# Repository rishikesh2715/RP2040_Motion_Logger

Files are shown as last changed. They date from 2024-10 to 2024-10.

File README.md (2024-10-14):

# RP2040 Motion Logger

<p align="center">
  <div>
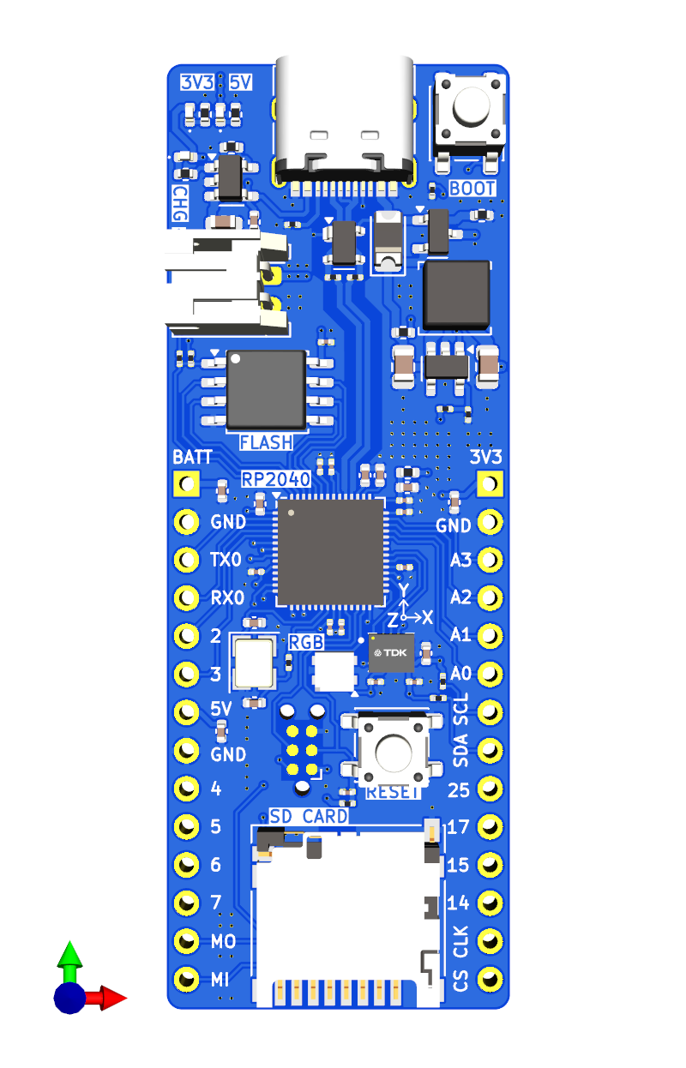
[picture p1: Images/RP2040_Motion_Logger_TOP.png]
    
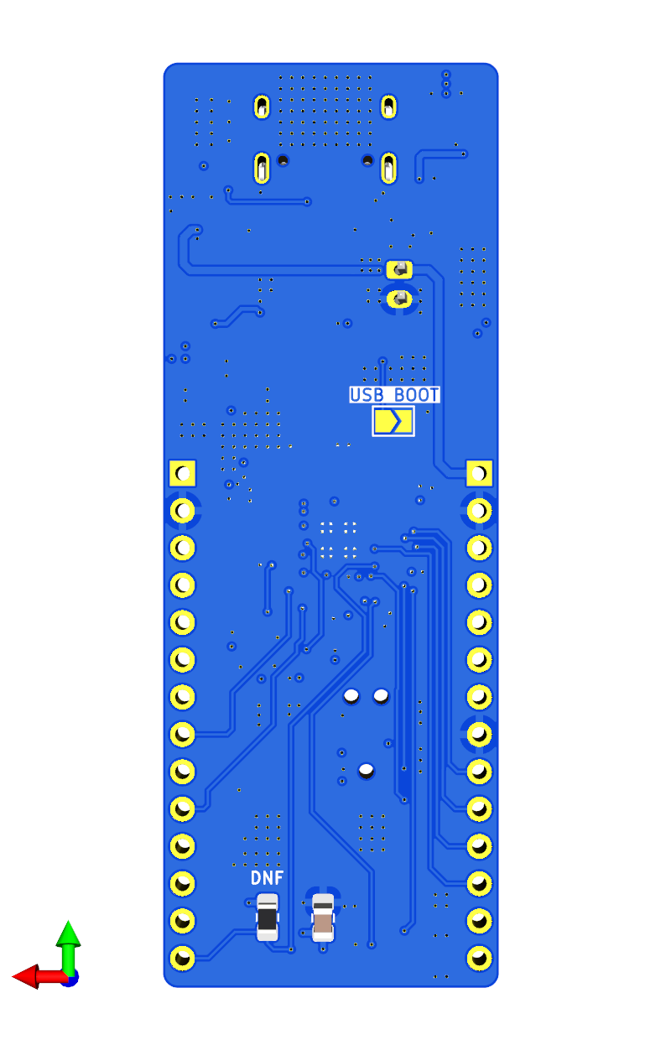
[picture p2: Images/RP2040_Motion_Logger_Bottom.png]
    
  </div>
  <div>
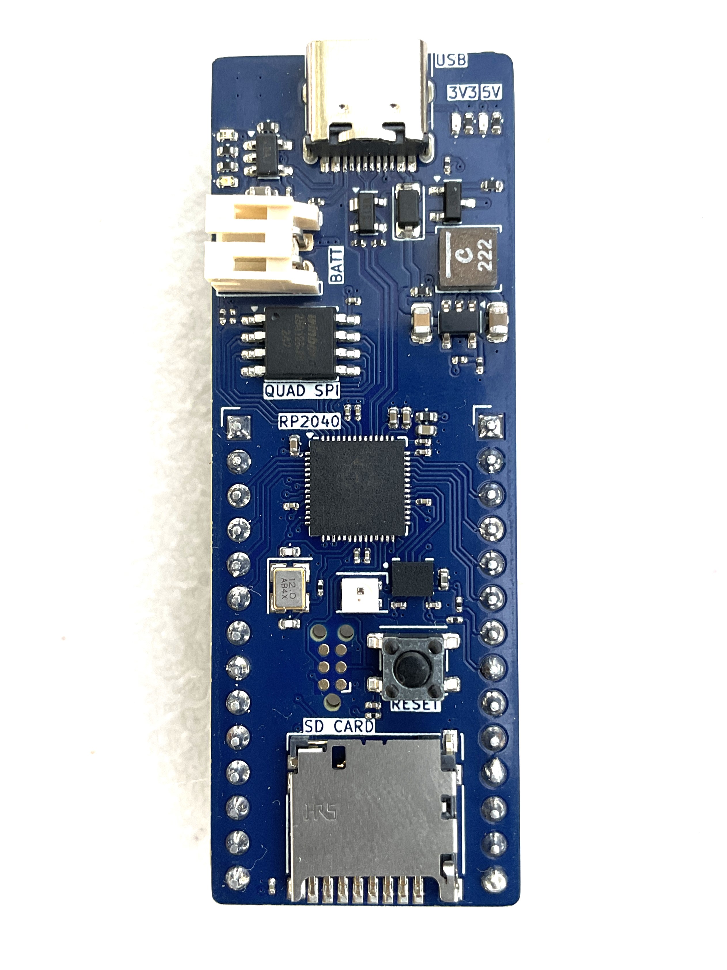
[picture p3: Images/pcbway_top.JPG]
    
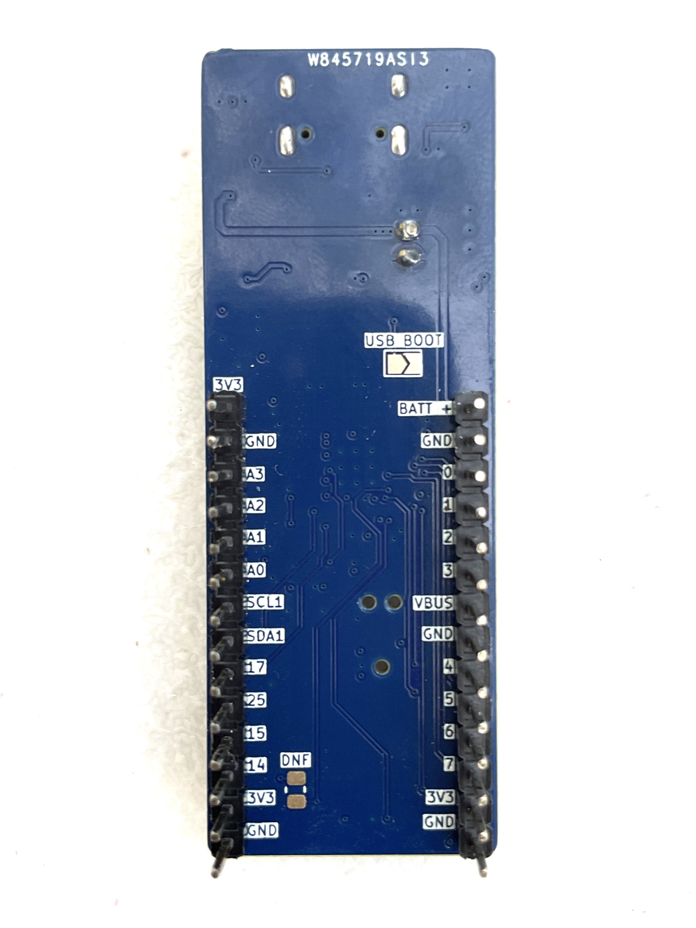
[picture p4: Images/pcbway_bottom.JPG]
    
  </div>
</p>

*I have slightly modified the board to include a bootloader button and made some aesthetic changes since having this board produced. Thus, the produced board slightly looks different. Everything else remains the same*

## Order this Board Through [PCBway](https://www.pcbway.com) 🛫

You can order this board through PCBway for excellent board quality and fast shipping at a very affordable rate. 

- Using PCBway as the manufacturer is recommended because the stackup for this board is based on their specifications. The differential impedance for the USB differential pair has been calculated based on PCBway’s stackup, ensuring that the board will perform as intended when manufactured with them.

- The Bill of Materials (BOM) provided is in PCBway's format. This compatibility ensures a smooth and reliable production experience, reducing the chances of delays due to part sourcing.

To order, simply upload the zip file to PCBway’s portal, select your preferences,
set the Min Track/spacing to 6/6 mil and set the min hole size to 0.2mm. Choosing Immersion Gold(ENIG) as the board finish is recommended but not required, and place your order. PCBway’s user-friendly interface allows for easy customization and order tracking from manufacturing to delivery.

You can learn more about PCBway at the end.

## Interactive PCB Viewer

You can view this board interactively on [KiCanvas](https://kicanvas.org/?github=https%3A%2F%2Fgithub.com%2Frishikesh2715%2FRP2040_Motion_Logger).

## Overview
The RP2040 Motion Logger is a custom microcontroller board based on the RP2040 chip, designed for motion data logging and versatile IoT applications. This compact board (0.9 x 2.48 inches) integrates a wide range of features, making it a powerful tool for projects requiring motion sensing, storage, and connectivity.

### Key Features:
- **Microcontroller**: RP2040 with dual ARM Cortex M0+ processors
- **Motion Sensor**: ICM-42688-P IMU for 6-axis motion tracking
- **Storage**: 128 Mbit Quad SPI Flash Memory and SD Card connector
- **Power Options**: USB Type-C connector or 1S LiPo/Li-ion battery
- **Battery Management**: Onboard charger for 1S LiPo/Li-ion batteries
- **LEDs**: Addressable RGB LED for user indications, plus power status LEDs for both 3.3V and 5V
- **Connectors**:
  - TC2030 JTAG Connector for programming and debugging
  - A set of pin headers including UART, I2C, SPI, ADC, and GPIO pins
- **Power Supply**: 3.3V buck converter supporting up to 2A current
- **Additional Features**: Reset and Bootloader buttons, ESD protection, USB Power, Battery Power, and 3.3V Power pins on headers

### Power Options:
The RP2040 Motion Logger can be powered either via the USB Type-C connector or a 1S LiPo/Li-ion battery. 

### Programming Options:
You can program the board through the USB Type-C connector or the TC2030 JTAG Connector.

## Getting Started
1. **Power Up**: Connect the board via USB Type-C or connect a 1S LiPo/Li-ion battery.
2. **Programming**: Use either the USB connection or JTAG connector with an appropriate debugger to flash your code. (I use VS Code with Raspberry PI PICO Extension)
3. **Bootloader Mode**: Hold down the Bootloader button while connecting the board to USB to enter bootloader mode.
4. **Data Logging**: Use the IMU and available storage to log motion data, or extend functionality via UART, I2C, SPI, and ADC pins.

## Hardware Pinout
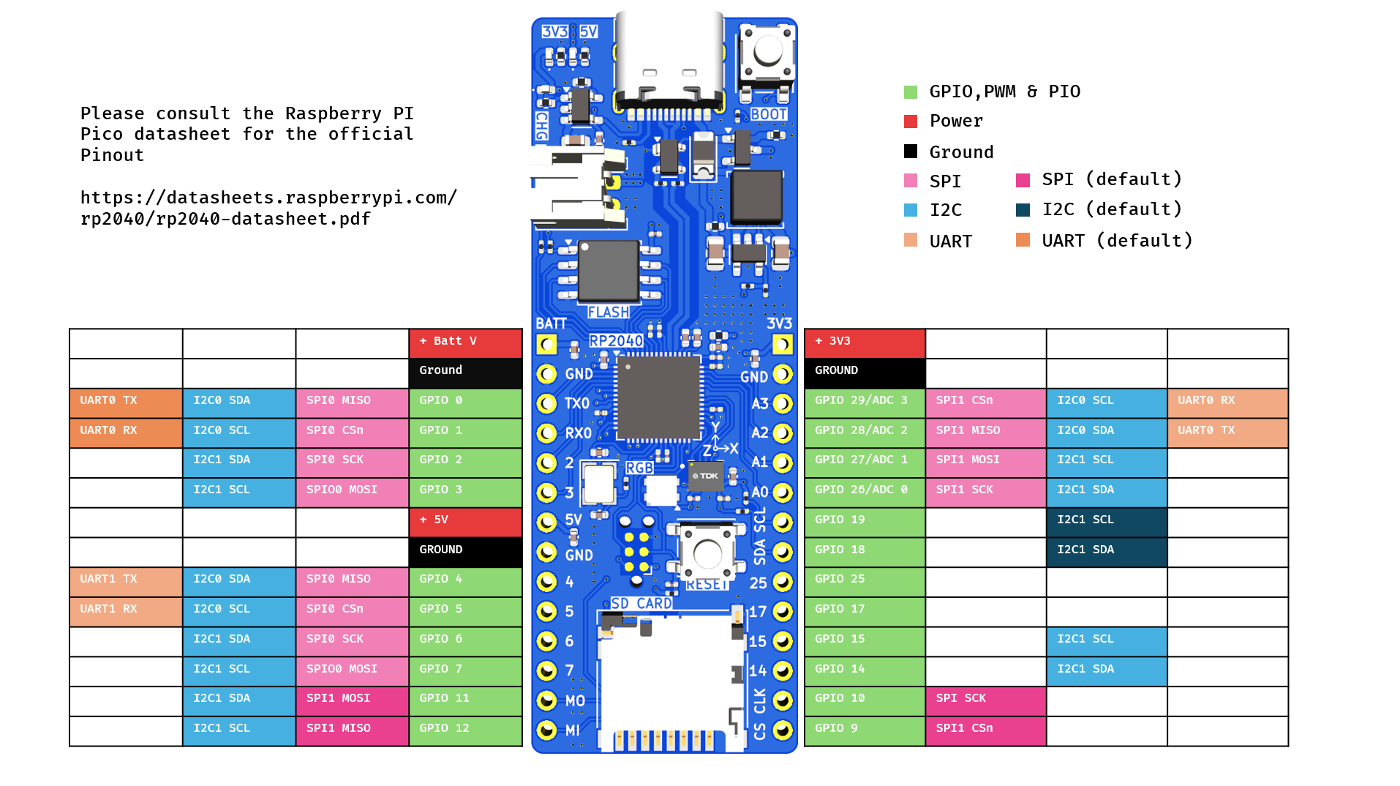
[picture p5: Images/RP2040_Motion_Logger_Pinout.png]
Pinout


*Note* In reality All the RP2040's GPIO Pins are capable of I2C, UART, SPI communications but I have intenionaly left some of the pins blank in the PINOUT diagram whenever I did not had a whole set of communication pins.

## PCBWay - PCB Manufacturing and Assembly
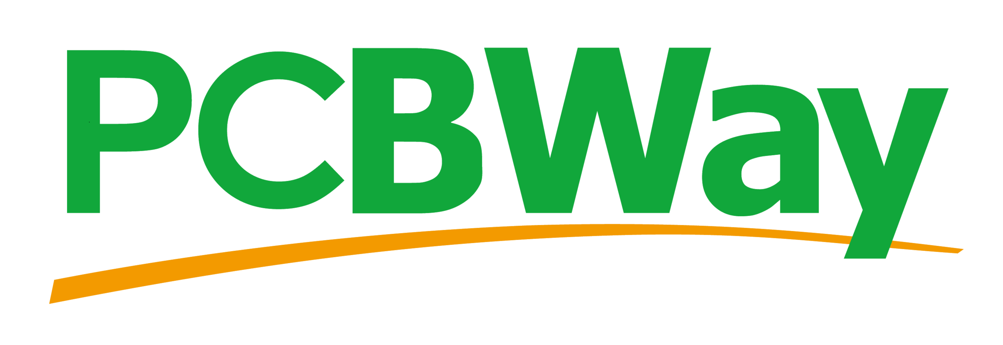
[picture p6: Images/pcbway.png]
PCBWay

This project was proudly sponsored by **PCBWay**, a leading PCB manufacturer and assembler. They provided high-quality PCB manufacturing and assembly services, ensuring that the RP2040 Motion Logger board was produced to the highest standards. Here’s why PCBWay is a great choice for PCB production:

- **Exceptional Quality**: The PCBs produced by PCBWay have excellent build quality, with precise soldering and thorough assembly.
- **Fast Service**: PCBWay offers quick turnaround times, so your project can stay on track.
- **Comprehensive Services**: From prototyping to mass production, PCBWay provides services for all stages of PCB development, including multi-layer PCBs, advanced PCBs, flexible PCBs, and assembly services.
- **Affordable Pricing**: PCBWay offers competitive pricing without compromising quality.

If you’re looking for a reliable partner to bring your PCB projects to life, check out PCBWay [here](https://pcbway.com/g/lGOcWf). With their extensive capabilities and top-notch customer support, PCBWay is the ideal choice for makers, engineers, and businesses alike.

## License
This project is open-source, licensed under the MIT License. Feel free to modify and distribute as per the license terms.

## Contributing
Contributions are welcome! Please fork the repository, make your changes, and submit a pull request.

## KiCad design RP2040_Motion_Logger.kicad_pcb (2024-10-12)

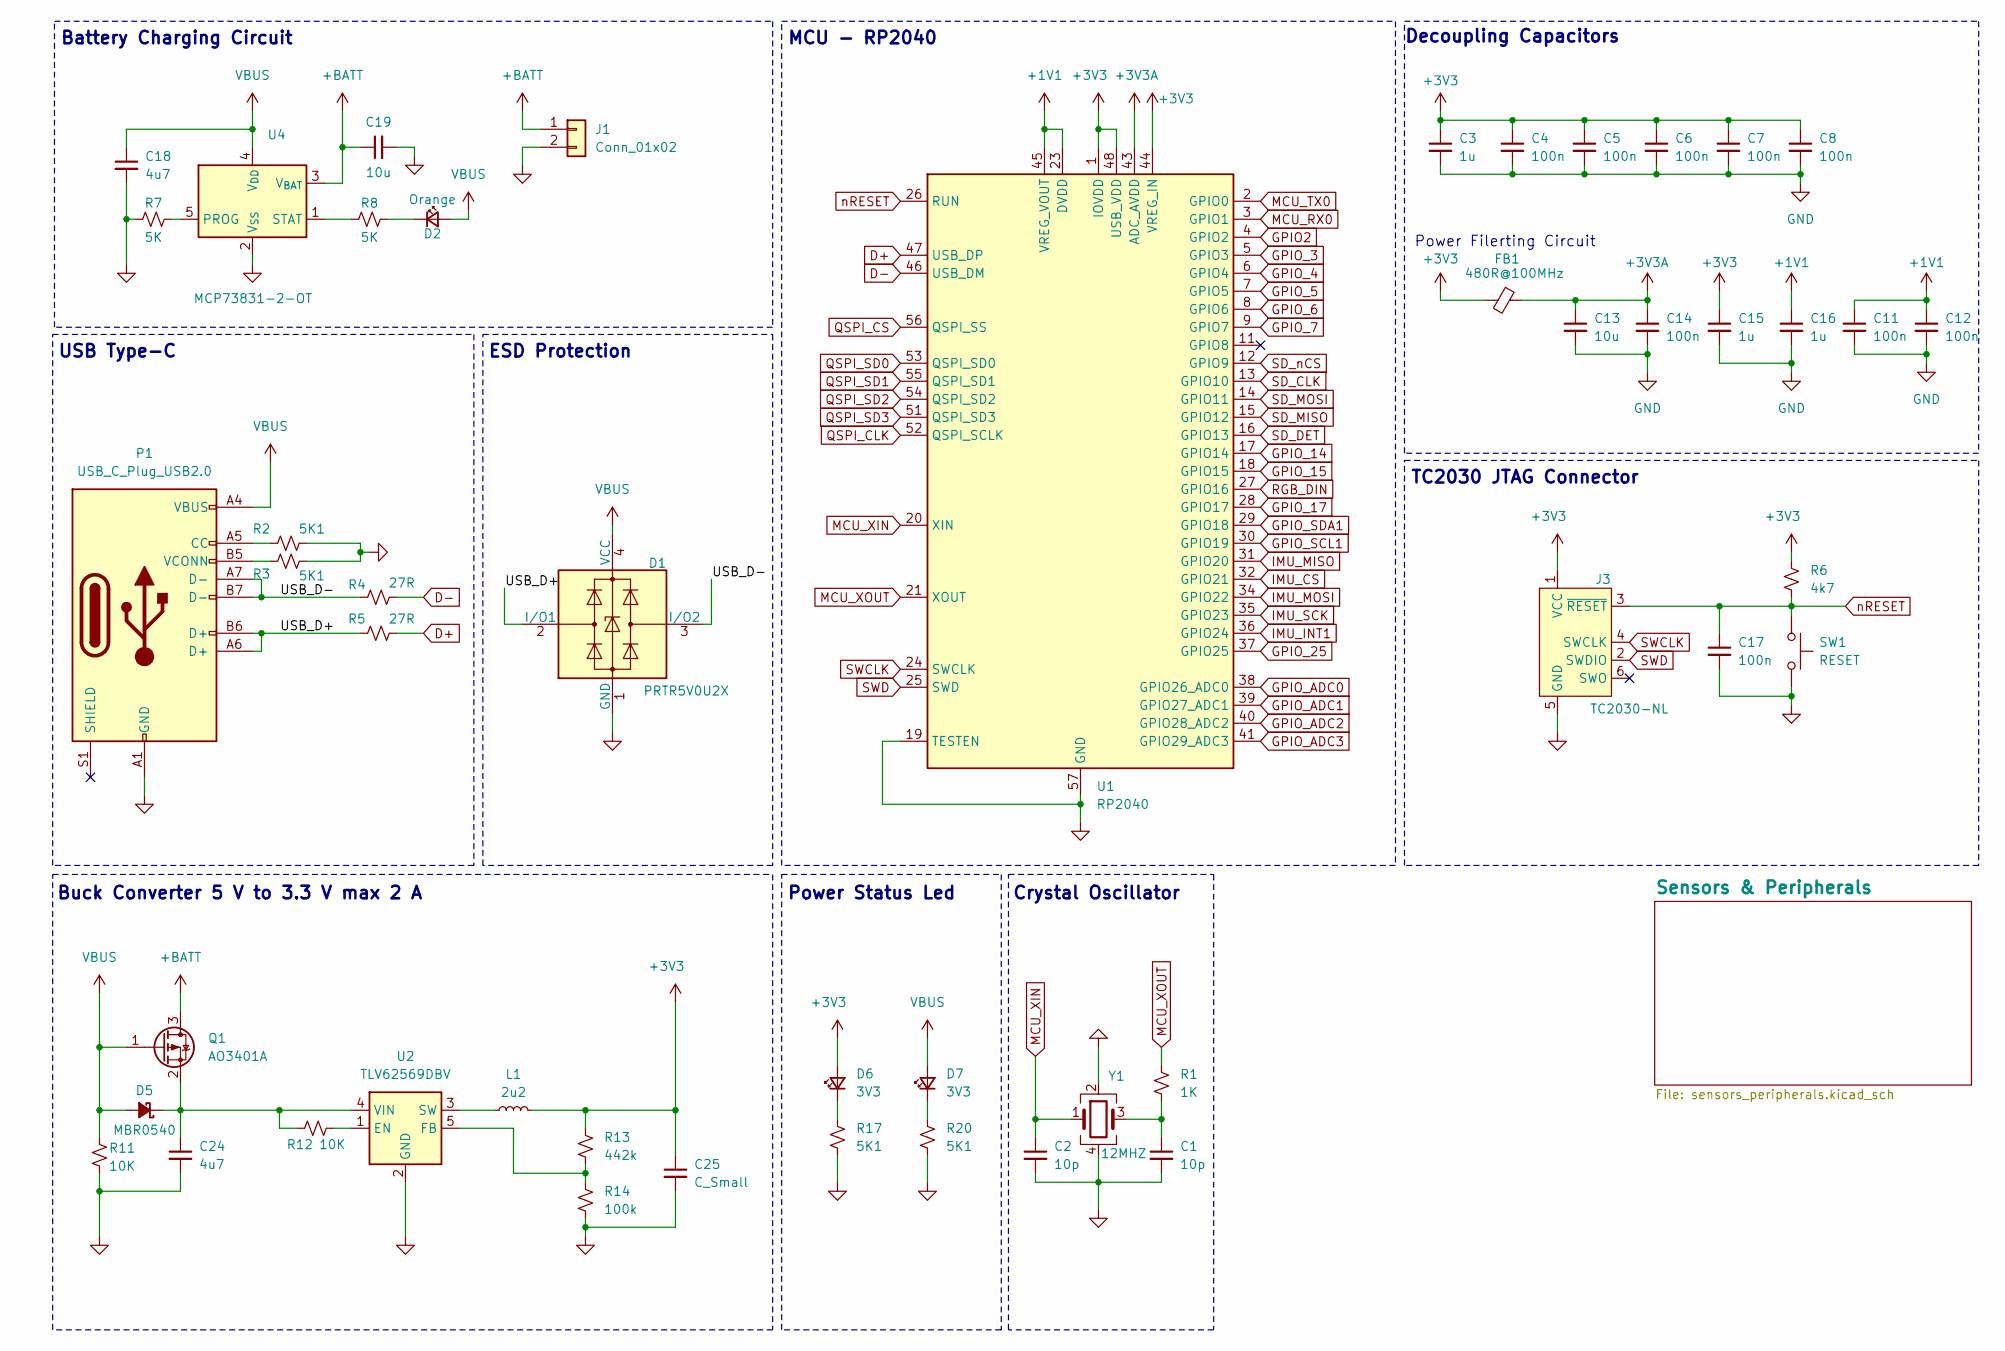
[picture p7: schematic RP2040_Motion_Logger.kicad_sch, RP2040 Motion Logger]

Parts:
C1, C2: 10p; C_0402_1005Metric
C3, C15, C16: 1u; C_0402_1005Metric
C4, C5, C6, C7, C8, C11, C12, C14, C17: 100n; C_0201_0603Metric
C13: 10u; C_0402_1005Metric
C18: 4u7; C_0402_1005Metric
C19: 10u; C_0603_1608Metric
C24: 4u7; C_0805_2012Metric
C25: C_Small; C_0805_2012Metric
D1: PRTR5V0U2X; SOT-143
D2: Orange; LED_0402_1005Metric
D5: MBR0540; D_1206_3216Metric
D6, D7: 3V3; LED_0402_1005Metric
FB1: 480R@100MHz; R_0402_1005Metric
J1: Conn_01x02; JST_PH_S2B-PH-K_1x02_P2.00mm_Horizontal
J3: TC2030-NL; Tag-Connect_TC2030-IDC-NL_2x03_P1.27mm_Vertical
L1: 2u2; L_Coilcraft_XAL4020-XXX
P1: USB_C_Plug_USB2.0; USB_C_Receptacle_HRO_TYPE-C-31-M-12
Q1: AO3401A; SOT-23
R1: 1K; R_0201_0603Metric
R2, R3: 5K1; R_0201_0603Metric
R4, R5: 27R; R_0201_0603Metric
R6: 4k7; R_0201_0603Metric
R7, R8: 5K; R_0402_1005Metric
R11, R12: 10K; R_0402_1005Metric
R13: 442k; R_0201_0603Metric
R14: 100k; R_0201_0603Metric
R17, R20: 5K1; R_0402_1005Metric
SW1: RESET; SW_SPST_PTS647_Sx38
U1: RP2040; QFN-56-1EP_7x7mm_P0.4mm_EP3.2x3.2mm
U2: TLV62569DBV; SOT-23-5
U4: MCP73831-2-OT; SOT-23-5
Y1: 12MHZ; Crystal_SMD_3225-4Pin_3.2x2.5mm

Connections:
+1V1: C11.1, C12.1, C16.1, U1.23 (DVDD), U1.45 (VREG_VOUT), U1.50 (DVDD)
+3V3: C3.1, C4.1, C5.1, C6.1, C7.1, C8.1, C15.1, C25.1, D6.2 (A), FB1.2, J3.1 (VCC), L1.2, R6.1, R13.1, U1.1 (IOVDD), U1.10 (IOVDD), U1.22 (IOVDD), U1.33 (IOVDD), U1.42 (IOVDD), U1.44 (VREG_IN), U1.48 (USB_VDD), U1.49 (IOVDD); also elsewhere on the board
+3V3A: C13.1, C14.1, FB1.1, U1.43 (ADC_AVDD)
+BATT: C19.1, J1.1, Q1.3 (D), U4.3 (V_{BAT}); also elsewhere on the board
/USB_D+: D1.2 (I/O1), P1.A6 (D+), P1.B6 (D+), R5.1
/USB_D-: D1.3 (I/O2), P1.A7 (D-), P1.B7 (D-), R4.1
D+: R5.2, U1.47 (USB_DP)
D-: R4.2, U1.46 (USB_DM)
GND: C1.2, C2.2, C3.2, C4.2, C5.2, C6.2, C7.2, C8.2, C11.2, C12.2, C13.2, C14.2, C15.2, C16.2, C17.2, C18.2, C19.2, C24.2, C25.2, D1.1 (GND), J1.2, J3.5 (GND), P1.A1 (GND), P1.A12 (GND), P1.B1 (GND), P1.B12 (GND), R2.2, R3.2, R7.1, R11.2, R14.2, R17.2, R20.2, SW1.2, U1.19 (TESTEN), U1.57 (GND), U2.2 (GND), U4.2 (V_{SS}), Y1.2, Y1.4; also elsewhere on the board
GPIO2: U1.4 (GPIO2); also elsewhere on the board
GPIO_3: U1.5 (GPIO3); also elsewhere on the board
GPIO_4: U1.6 (GPIO4); also elsewhere on the board
GPIO_5: U1.7 (GPIO5); also elsewhere on the board
GPIO_6: U1.8 (GPIO6); also elsewhere on the board
GPIO_7: U1.9 (GPIO7); also elsewhere on the board
GPIO_14: U1.17 (GPIO14); also elsewhere on the board
GPIO_15: U1.18 (GPIO15); also elsewhere on the board
GPIO_17: U1.28 (GPIO17); also elsewhere on the board
GPIO_25: U1.37 (GPIO25); also elsewhere on the board
GPIO_ADC0: U1.38 (GPIO26_ADC0); also elsewhere on the board
GPIO_ADC1: U1.39 (GPIO27_ADC1); also elsewhere on the board
GPIO_ADC2: U1.40 (GPIO28_ADC2); also elsewhere on the board
GPIO_ADC3: U1.41 (GPIO29_ADC3); also elsewhere on the board
GPIO_SCL1: U1.30 (GPIO19); also elsewhere on the board
GPIO_SDA1: U1.29 (GPIO18); also elsewhere on the board
IMU_CS: U1.32 (GPIO21); also elsewhere on the board
IMU_INT1: U1.36 (GPIO24); also elsewhere on the board
IMU_MISO: U1.31 (GPIO20); also elsewhere on the board
IMU_MOSI: U1.34 (GPIO22); also elsewhere on the board
IMU_SCK: U1.35 (GPIO23); also elsewhere on the board
MCU_RX0: U1.3 (GPIO1); also elsewhere on the board
MCU_TX0: U1.2 (GPIO0); also elsewhere on the board
MCU_XIN: C2.1, U1.20 (XIN), Y1.1
MCU_XOUT: R1.1, U1.21 (XOUT)
unnamed: C1.1, R1.2, Y1.3
unnamed: D2.1 (K), R8.2
unnamed: C24.1, D5.1 (K), Q1.2 (S), R12.1, U2.4 (VIN)
unnamed: D6.1 (K), R17.1
unnamed: D7.1 (K), R20.1
unnamed: P1.A5 (CC), R2.1
unnamed: P1.B5 (VCONN), R3.1
unnamed: R12.2, U2.1 (EN)
unnamed: R13.2, R14.1, U2.5 (FB)
unnamed: L1.1, U2.3 (SW)
unnamed: R7.2, U4.5 (PROG)
unnamed: R8.1, U4.1 (STAT)
QSPI_CLK: U1.52 (QSPI_SCLK); also elsewhere on the board
QSPI_CS: U1.56 (QSPI_SS); also elsewhere on the board
QSPI_SD0: U1.53 (QSPI_SD0); also elsewhere on the board
QSPI_SD1: U1.55 (QSPI_SD1); also elsewhere on the board
QSPI_SD2: U1.54 (QSPI_SD2); also elsewhere on the board
QSPI_SD3: U1.51 (QSPI_SD3); also elsewhere on the board
RGB_DIN: U1.27 (GPIO16); also elsewhere on the board
SD_CLK: U1.13 (GPIO10); also elsewhere on the board
SD_DET: U1.16 (GPIO13); also elsewhere on the board
SD_MISO: U1.15 (GPIO12); also elsewhere on the board
SD_MOSI: U1.14 (GPIO11); also elsewhere on the board
SD_nCS: U1.12 (GPIO9); also elsewhere on the board
SWCLK: J3.4 (SWCLK), U1.24 (SWCLK)
SWD: J3.2 (SWDIO), U1.25 (SWD)
VBUS: C18.1, D1.4 (VCC), D2.2 (A), D5.2 (A), D7.2 (A), P1.A4 (VBUS), P1.A9 (VBUS), P1.B4 (VBUS), P1.B9 (VBUS), Q1.1 (G), R11.1, U4.4 (V_{DD}); also elsewhere on the board
nRESET: C17.1, J3.3 (~RESET), R6.2, SW1.1, U1.26 (RUN)

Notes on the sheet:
Battery Charging Circuit
Crystal Oscillator
USB Type-C
ESD Protection
TC2030 JTAG Connector
Power Status Led
MCU - RP2040
Power Filerting Circuit
Buck Converter 5 V to 3.3 V max 2 A
Decoupling Capacitors

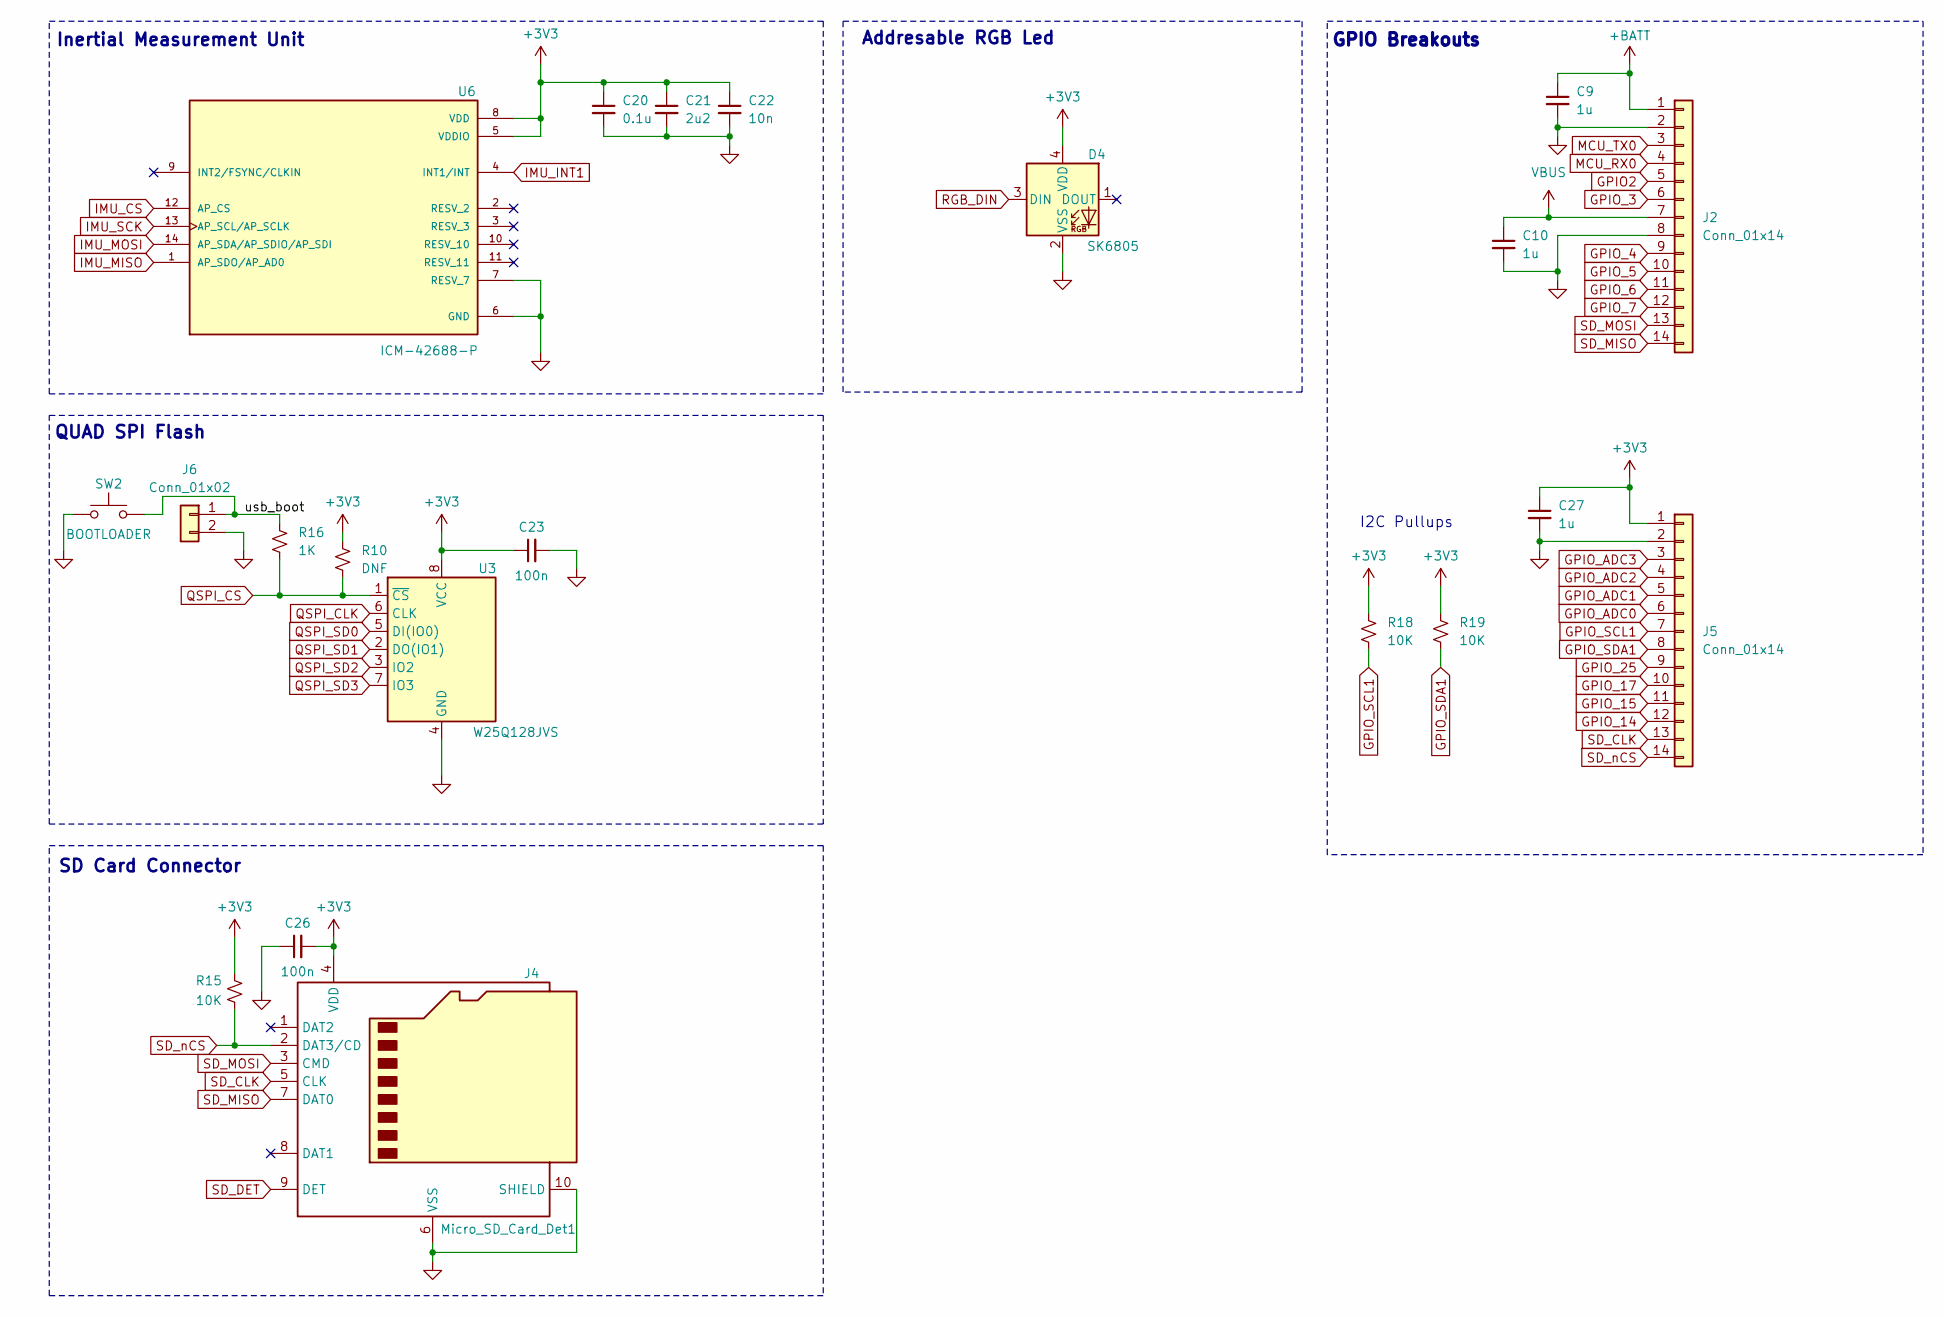
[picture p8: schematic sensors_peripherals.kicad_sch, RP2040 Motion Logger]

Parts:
C9, C10, C27: 1u; C_0402_1005Metric
C20: 0.1u; C_0201_0603Metric
C21: 2u2; C_0402_1005Metric
C22: 10n; C_0201_0603Metric
C23: 100n; C_0201_0603Metric
C26: 100n; C_0805_2012Metric_Pad1.18x1.45mm_HandSolder
D4: SK6805; LED_SK6805_PLCC4_2.4x2.7mm_P1.3mm
J2, J5: Conn_01x14; PinHeader_1x14_P2.54mm_Vertical
J4: Micro_SD_Card_Det1; microSD_HC_Hirose_DM3D-SF
J6: Conn_01x02; SolderJumper-2_P1.3mm_Open_TrianglePad1.0x1.5mm
R10: DNF; R_0201_0603Metric
R15: 10K; R_0805_2012Metric_Pad1.20x1.40mm_HandSolder
R16: 1K; R_0201_0603Metric
R18, R19: 10K; R_0201_0603Metric
SW2: BOOTLOADER; SW_SPST_PTS647_Sx38
U3: W25Q128JVS; SOIC-8_5.23x5.23mm_P1.27mm
U6: ICM-42688-P; PQFN50P300X250X97-14N; PARTREV 1.2

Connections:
+3V3: C20.1, C21.1, C22.1, C23.1, C26.2, C27.1, D4.4 (VDD), J4.4 (VDD), J5.1, R10.1, R15.1, R18.1, R19.1, U3.8 (VCC), U6.5 (VDDIO), U6.8 (VDD); also elsewhere on the board
+BATT: C9.1, J2.1; also elsewhere on the board
/Sensors & Peripherals/usb_boot: J6.1, R16.1, SW2.2
GND: C9.2, C10.2, C20.2, C21.2, C22.2, C23.2, C26.1, C27.2, D4.2 (VSS), J2.2, J2.8, J4.6 (VSS), J4.10 (SHIELD), J5.2, J6.2, SW2.1, U3.4 (GND), U6.6 (GND), U6.7 (RESV_7); also elsewhere on the board
GPIO2: J2.5; also elsewhere on the board
GPIO_3: J2.6; also elsewhere on the board
GPIO_4: J2.9; also elsewhere on the board
GPIO_5: J2.10; also elsewhere on the board
GPIO_6: J2.11; also elsewhere on the board
GPIO_7: J2.12; also elsewhere on the board
GPIO_14: J5.12; also elsewhere on the board
GPIO_15: J5.11; also elsewhere on the board
GPIO_17: J5.10; also elsewhere on the board
GPIO_25: J5.9; also elsewhere on the board
GPIO_ADC0: J5.6; also elsewhere on the board
GPIO_ADC1: J5.5; also elsewhere on the board
GPIO_ADC2: J5.4; also elsewhere on the board
GPIO_ADC3: J5.3; also elsewhere on the board
GPIO_SCL1: J5.7, R18.2; also elsewhere on the board
GPIO_SDA1: J5.8, R19.2; also elsewhere on the board
IMU_CS: U6.12 (AP_CS); also elsewhere on the board
IMU_INT1: U6.4 (INT1/INT); also elsewhere on the board
IMU_MISO: U6.1 (AP_SDO/AP_AD0); also elsewhere on the board
IMU_MOSI: U6.14 (AP_SDA/AP_SDIO/AP_SDI); also elsewhere on the board
IMU_SCK: U6.13 (AP_SCL/AP_SCLK); also elsewhere on the board
MCU_RX0: J2.4; also elsewhere on the board
MCU_TX0: J2.3; also elsewhere on the board
QSPI_CLK: U3.6 (CLK); also elsewhere on the board
QSPI_CS: R10.2, R16.2, U3.1 (~CS); also elsewhere on the board
QSPI_SD0: U3.5 (DI(IO0)); also elsewhere on the board
QSPI_SD1: U3.2 (DO(IO1)); also elsewhere on the board
QSPI_SD2: U3.3 (IO2); also elsewhere on the board
QSPI_SD3: U3.7 (IO3); also elsewhere on the board
RGB_DIN: D4.3 (DIN); also elsewhere on the board
SD_CLK: J4.5 (CLK), J5.13; also elsewhere on the board
SD_DET: J4.9 (DET); also elsewhere on the board
SD_MISO: J2.14, J4.7 (DAT0); also elsewhere on the board
SD_MOSI: J2.13, J4.3 (CMD); also elsewhere on the board
SD_nCS: J4.2 (DAT3/CD), J5.14, R15.2; also elsewhere on the board
VBUS: C10.1, J2.7; also elsewhere on the board

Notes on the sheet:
QUAD SPI Flash
SD Card Connector
GPIO Breakouts
I2C Pullups
Inertial Measurement Unit
Addresable RGB Led

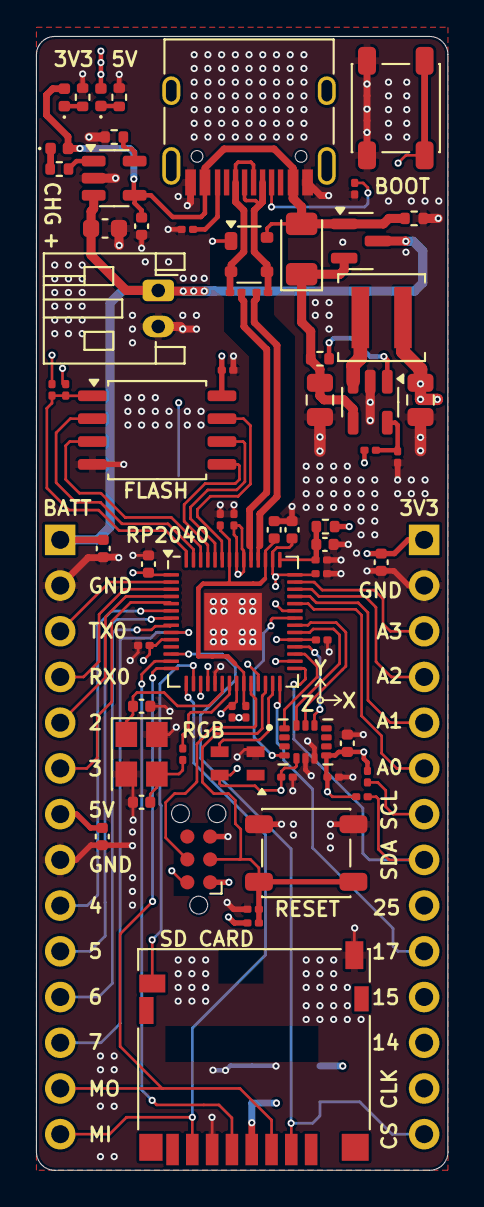
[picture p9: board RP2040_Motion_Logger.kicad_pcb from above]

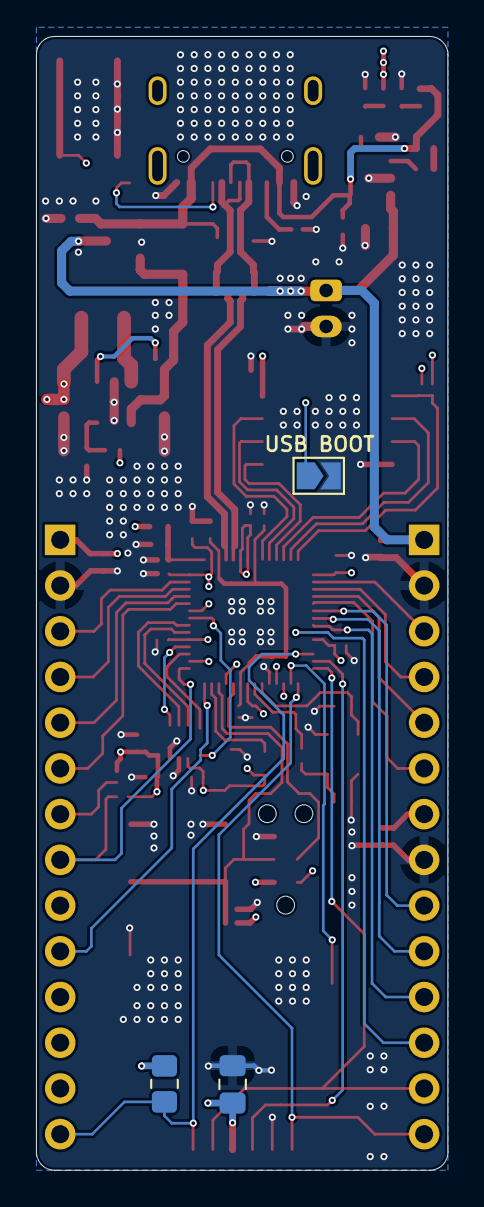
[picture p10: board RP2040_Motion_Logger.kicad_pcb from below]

Board: 4 copper layers, 22.9 x 63.0 mm, 70 parts (3 on the bottom side), 63 nets.

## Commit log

2024-10-02 Completed PCB
    [RP2040_Motion_Logger.kicad_pcb, RP2040_Motion_Logger.kicad_sch, sensors_peripherals.kicad_sch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]
2024-10-11 made some schematic aesthetic changes
    [RP2040_Motion_Logger.kicad_sch, sensors_peripherals.kicad_sch]
2024-10-12 Added a bootloader button and made some other QOL changes... mostly aesthetic.
    [MCU.kicad_sch, RP2040_Motion_Logger.kicad_pcb, RP2040_Motion_Logger.kicad_sch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]
2024-10-12 removed the DNF silkscreen for the SD Card connector's CS pin pullup resistor
    [RP2040_Motion_Logger.kicad_pcb, sensors_peripherals.kicad_sch]
